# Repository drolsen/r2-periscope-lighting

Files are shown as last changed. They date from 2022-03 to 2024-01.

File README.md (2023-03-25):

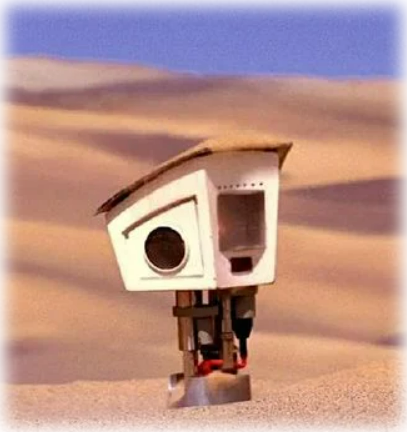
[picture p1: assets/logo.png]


# Open Source R2D2 Periscope Lighting PCB(s)

This open source project is a place to house all information around:
- Purchasing R2D2 periscope lighting PCBs
- Constructing the PCBs
- Uploading Code / Testing & running PCB lights

## Features
- [Deisgned for R2 Uppity Spinner](https://astromech.net/forums/showthread.php?42923-Uppity-Spinner-Periscope-Lifter-and-Rotary-PCB)
- Optional RX/TX communication
- 31x 5v WS2812B-2020 RGB LEDs
- 8 different lighting modes

<!---
## Assembily options

Before you get started on purchasing PCBs, you must first decide if you or the manufacturer will be surface mounting the PCB components. Its recommended you review both assembily options first before making any purchase. In both instances you get 5 whole kits, however one is less expensive than the other but requires more work.

- Minimal amount of soldering / Most Expensive
- Most amount of soldering / Least Expensive route

Minimal amount of soldering assembily option is the most expensive option cause the PCB circiut board manufacturer will be doing all the component (RGB LED, capacitors, resitors) for you under a 4 design x5 board run. This leaves you with only having to break out each PCB side, dry fitting them and soldering the through holes where each side edges meet. Upload code, apply power and away you go.

However the cheaper option requires the most amount of soldering and that you have experince at SMD soldering. Instead of the manufacturer doing the soldering you are given a metal stencile that is used in conjunction with low temp solder, heat gun or plate to surface mount self purchased components. This all before even assembiling the sides together, mounting arduino, uploading code and applying power.
-->

<!---## Ordering Guides

- Quick Assembly PCB Order Option (https://github.com/drolsen/r2-periscope-lighting/wiki/Ordering-PCBs)
 Complex Assembily PCB Order Option (https://github.com/drolsen/r2-periscope-lighting/wiki/PCB-Ordering-(Complex-Assembly)) -->

## Guides

All the gudies on ordering and assembly can be found in the wiki of this github repo:
https://github.com/drolsen/r2-periscope-lighting/wiki

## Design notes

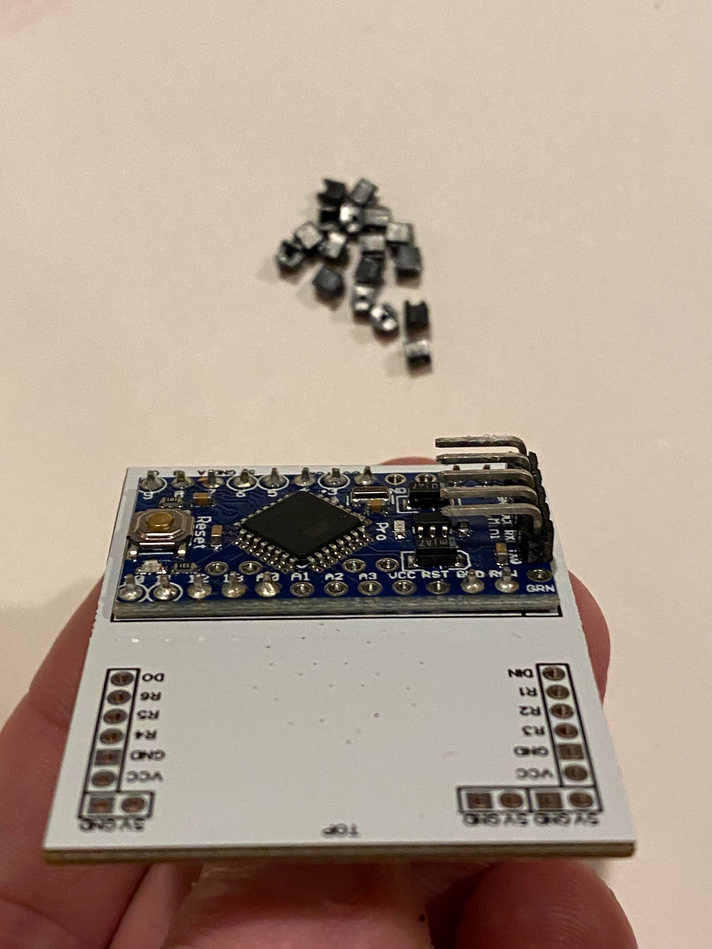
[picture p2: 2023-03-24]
assets/330232331_593315286163290_5333872589423925475_n.jpg

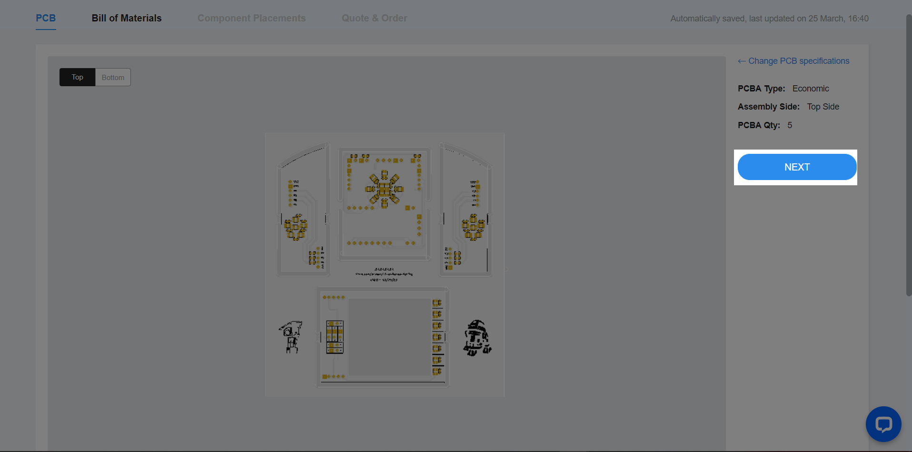
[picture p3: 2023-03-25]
assets/fab-04a.jpg

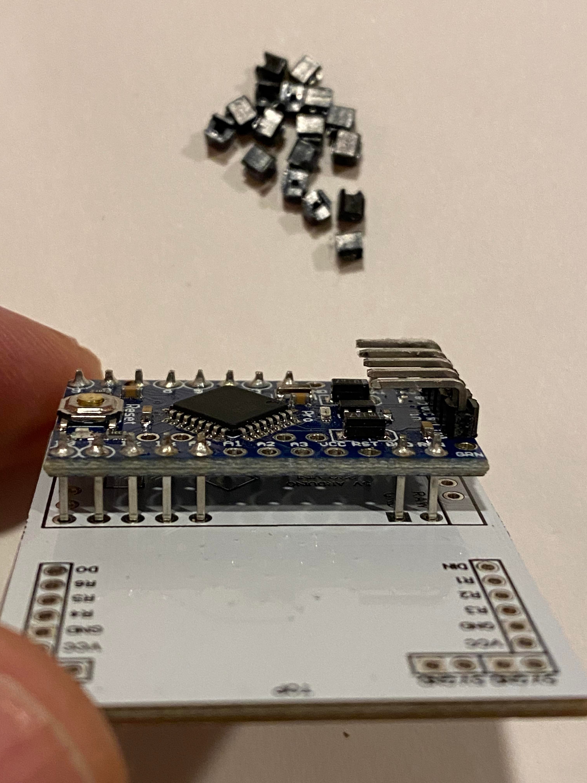
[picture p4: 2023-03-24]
assets/336629106_527774112630229_1906755230113006917_n.jpg

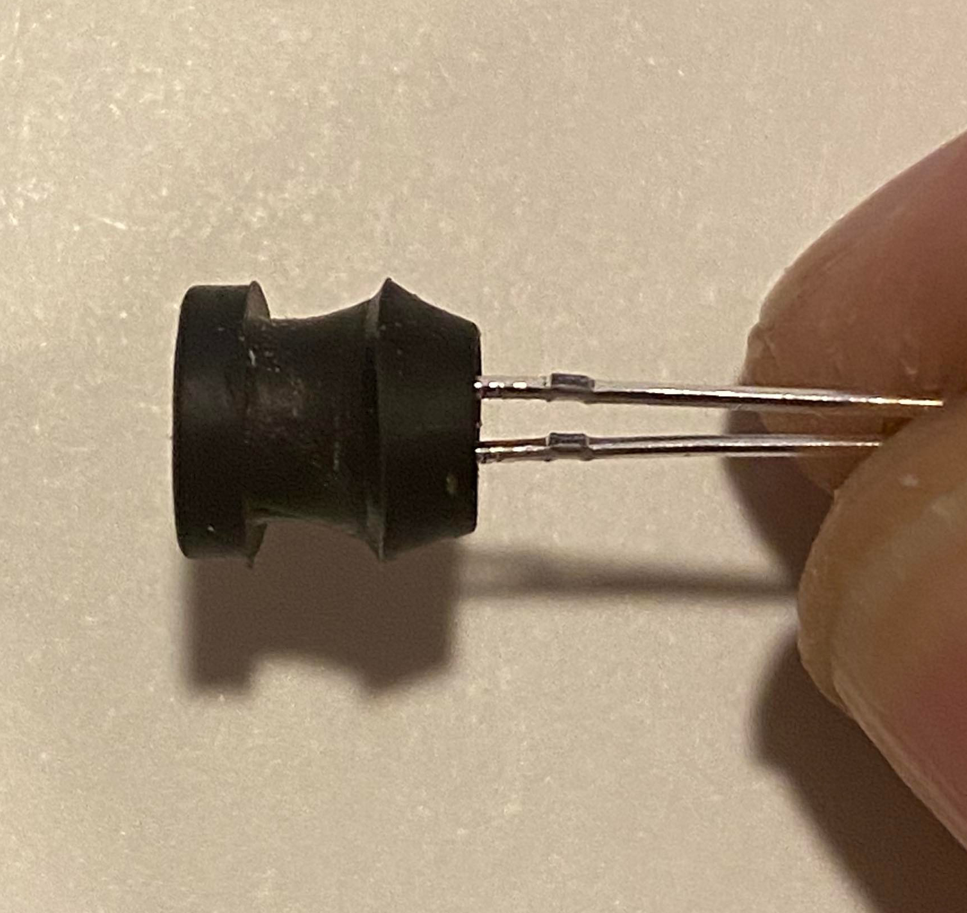
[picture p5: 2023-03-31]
assets/337446692_172143675710304_596749577539224145_n.jpg

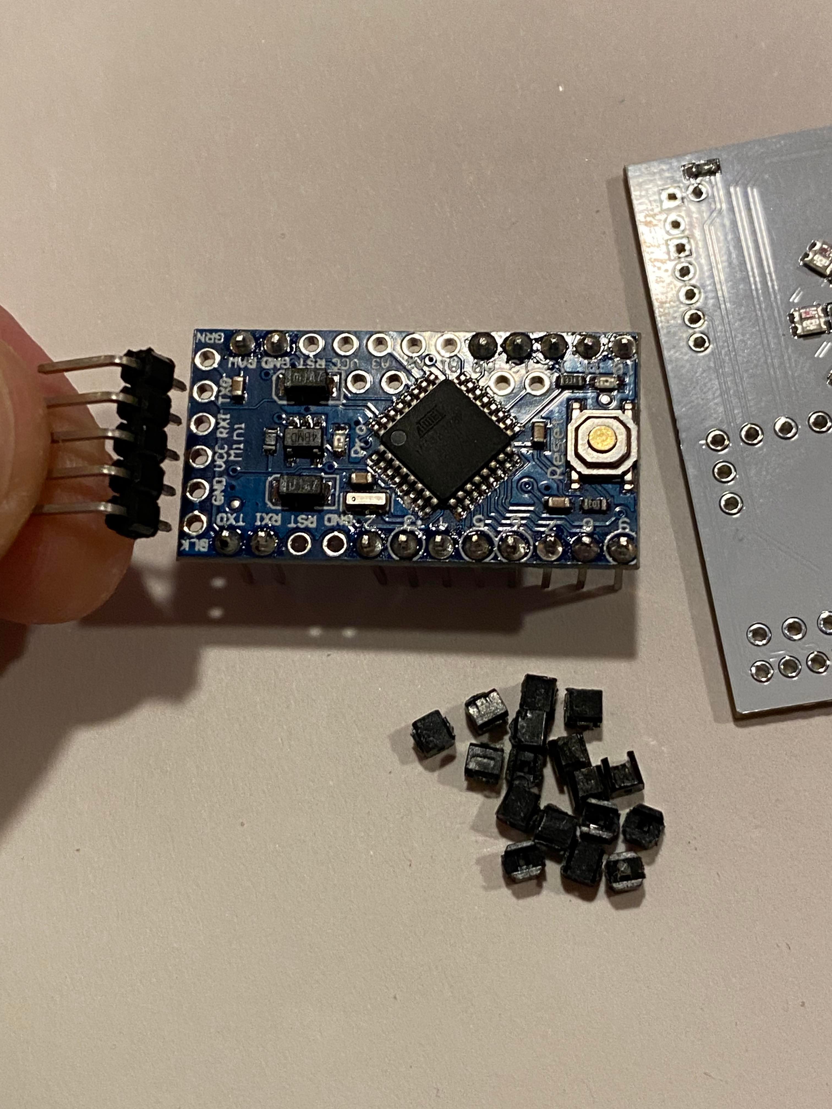
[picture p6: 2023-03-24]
assets/336670627_171413809047904_7290120640967253757_n.jpg

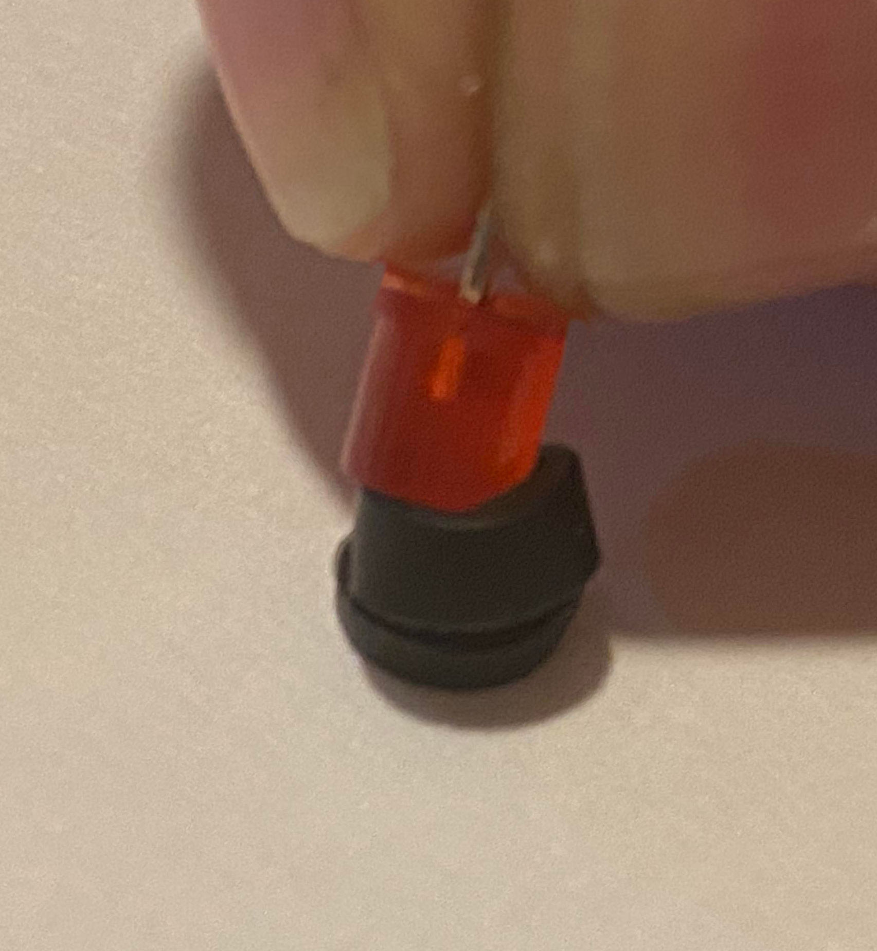
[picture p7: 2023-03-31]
assets/337642645_714867343767022_3792772655546986690_n.jpg

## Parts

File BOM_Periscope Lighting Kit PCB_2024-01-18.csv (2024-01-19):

ID | Name | Designator | Footprint | Quantity | Manufacturer Part | Manufacturer | Supplier | Supplier Part | Price
1 | LED-SMD_4P-L2.0-W2.0-TL_WS2812B-2020 | LED28,LED27,LED45,LED46,LED47,LED48,LED49,LED50,LED51,LED52,LED53,LED17,LED22,LED23,LED24,LED25,LED26,LED43,LED44,LED18,LED19,LED20,LED21,LED42,LED36,LED35,LED34,LED33,LED32,LED31,LED30 | LED-SMD_4P-L2.0-W2.0-TL_WS2812B-2020 | 31 | WS2812B-2020 | Worldsemi | LCSC | C965555 | 0.1
2 | C0402 | C1,C60,C61,C62,C63,C64,C65,C66,C67,C68,C69,C70,C71,C72,C73,C74,C75,C76,C77,C78,C79,C80,C81,C82,C83,C84,C85,C86,C87,C88,C89 | C0402 | 31 | CSA0402X7R104K250GT | HRE(芯声) | LCSC | C3015120 | 0.001
3 | R0603 | R4,R25,R26,R27,R28,R29,R30,R31,R32 | R0603 | 9 | RC0603FR-07150RL | YAGEO(国巨) | LCSC | C114608 | 0.001

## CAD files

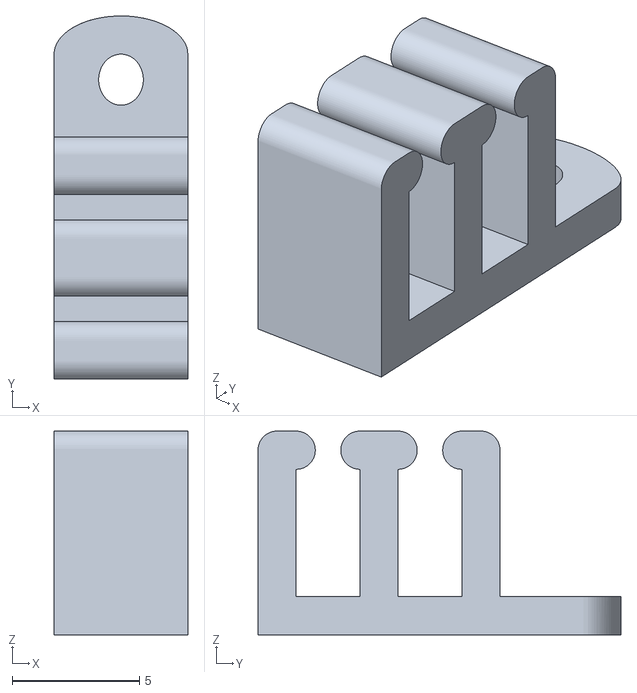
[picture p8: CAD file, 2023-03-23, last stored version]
models/Dome - STL/Holoprojector/Comb HP 2-B.stl
5.25 x 14.2 x 8.00

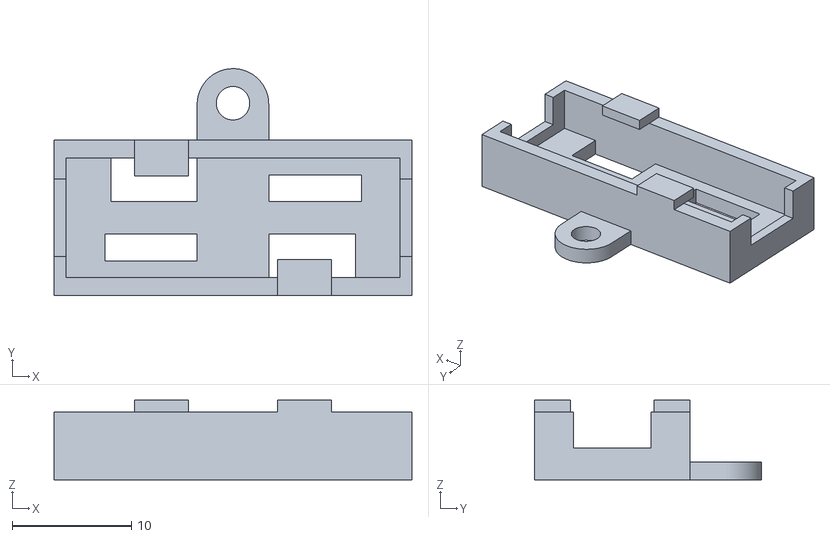
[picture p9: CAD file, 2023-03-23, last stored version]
models/Dome - STL/Servo Clips/Servoclip Mod1 - 1.stl
30.0 x 19.0 x 6.70

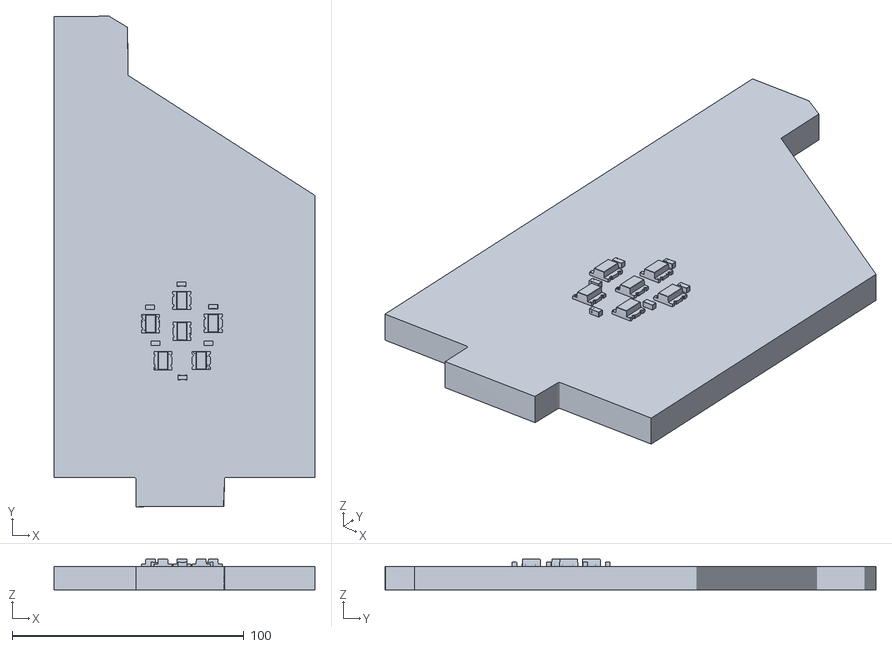
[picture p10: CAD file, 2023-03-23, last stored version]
models/OBJ_SideB.obj
112.5 x 211.4 x 13.3

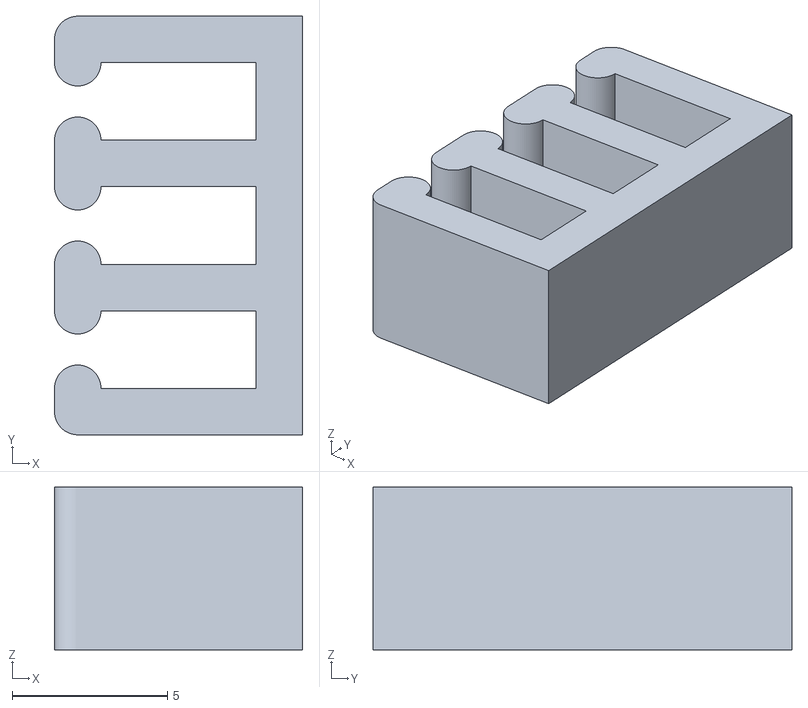
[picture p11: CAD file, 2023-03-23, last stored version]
models/Dome - STL/Combs/Comb 3x1 rev0.stl
8.00 x 13.5 x 5.25

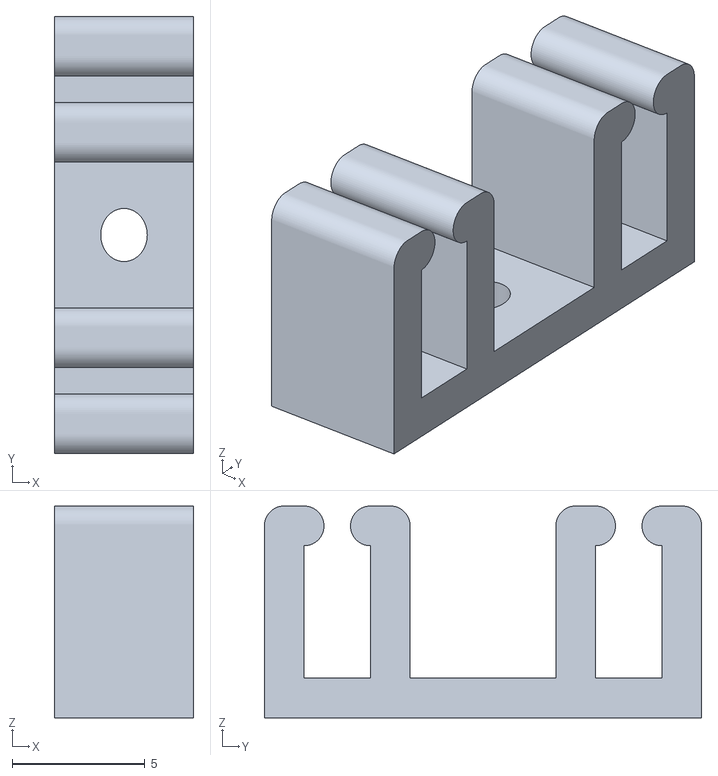
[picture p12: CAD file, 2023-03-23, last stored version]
models/Dome - STL/Holoprojector/Comb HP 2-B-2.stl
5.25 x 16.5 x 8.00

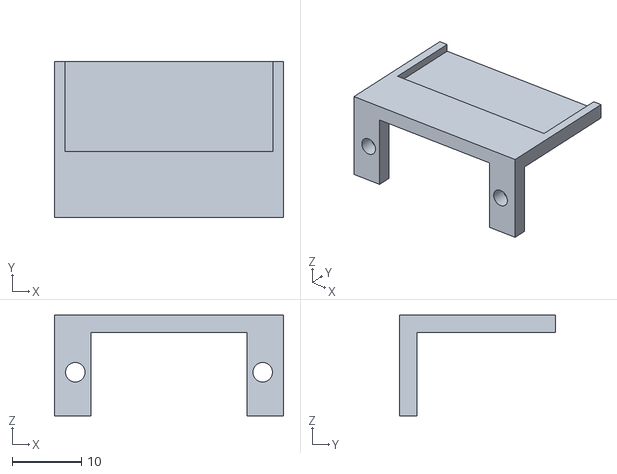
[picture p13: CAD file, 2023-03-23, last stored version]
models/Dome - STL/Servo Clips/Servoclip Base 1.stl
33.0 x 22.5 x 14.5

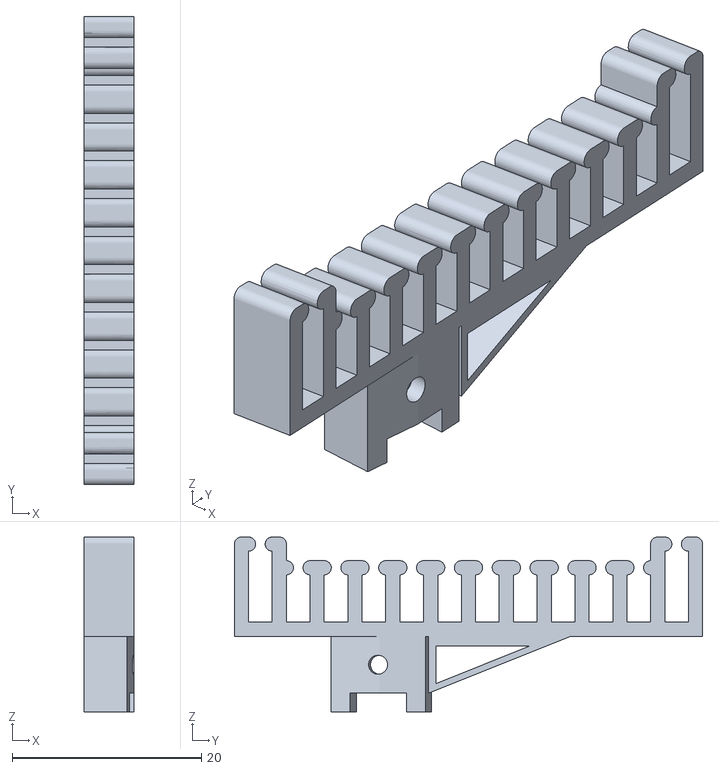
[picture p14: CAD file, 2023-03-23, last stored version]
models/Dome - STL/Tower & Combs/Tower Comb - Right11 Rev6.stl
5.25 x 49.5 x 18.5

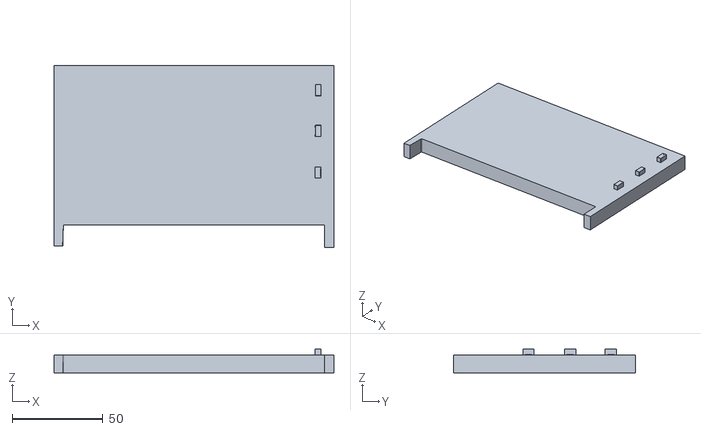
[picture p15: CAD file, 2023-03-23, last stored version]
models/OBJ_TopA.obj
153.9 x 99.9 x 13.1

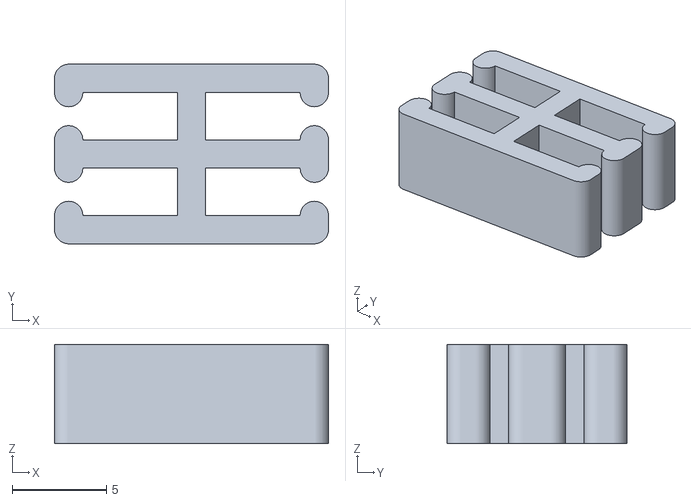
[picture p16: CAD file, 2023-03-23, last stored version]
models/Dome - STL/Combs/Comb 2x2 rev0.stl
14.5 x 9.50 x 5.25

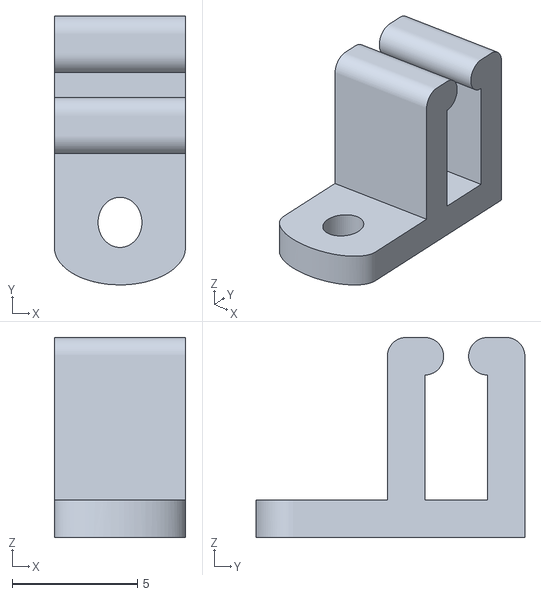
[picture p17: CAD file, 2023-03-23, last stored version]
models/Dome - STL/Holoprojector/Comb HP 1-B.stl
5.25 x 10.8 x 8.00

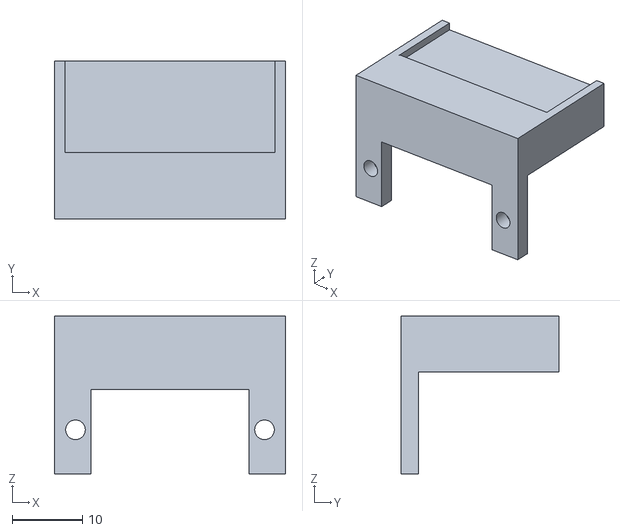
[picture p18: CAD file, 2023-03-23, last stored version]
models/Dome - STL/Servo Clips/Servoclip Base 1 - Tall.stl
33.0 x 22.5 x 22.5

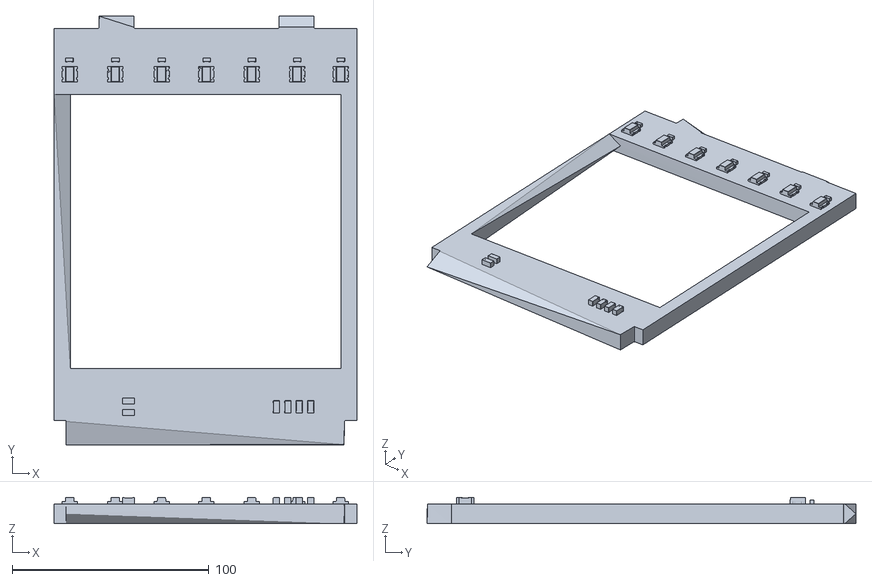
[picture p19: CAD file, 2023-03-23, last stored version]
models/OBJ_Front.obj
153.9 x 217.8 x 13.3

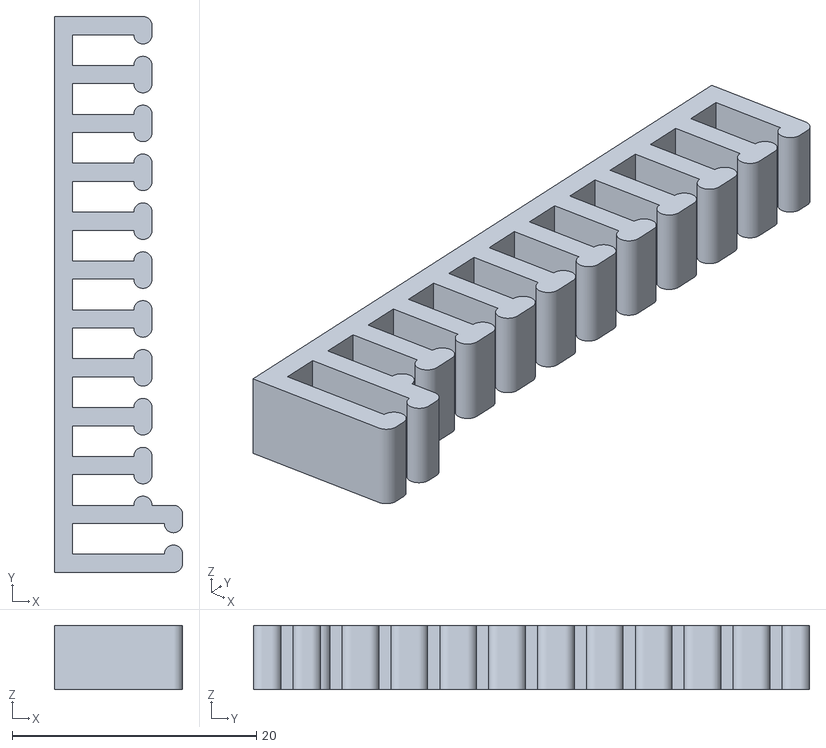
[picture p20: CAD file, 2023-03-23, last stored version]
models/Dome - STL/Combs/Comb 10x1 rev1.stl
10.5 x 45.5 x 5.25

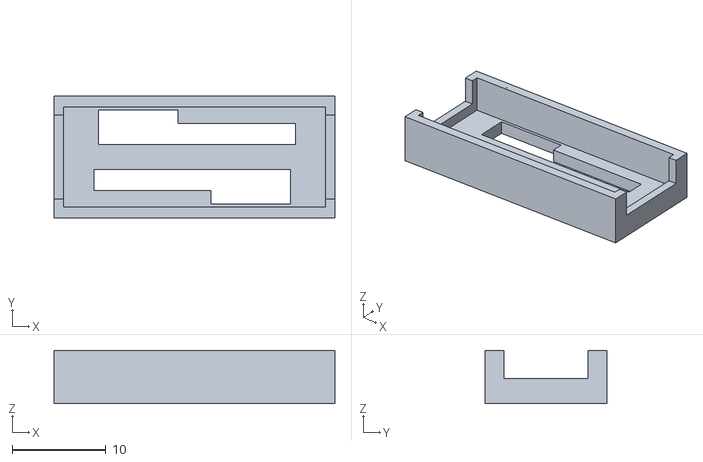
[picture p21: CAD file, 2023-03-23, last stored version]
models/Dome - STL/Servo Clips/Servoclip version2.stl
30.0 x 13.0 x 5.70

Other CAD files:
models/Dome - STL/Tower & Combs/Tower Comb - Left10 Rev5.stl
models/OBJ_Bottom.obj
models/Dome - STL/Combs/Comb 5x2 rev0.stl
models/Dome - STL/Servo Clips/Servoclip Base 2.stl
models/Dome - STL/Combs/Comb 10x1 rev0.stl
models/Dome - STL/Servo Clips/Servoclip Mod1 - 2.stl
models/Dome - STL/Servo Clips/Servoclip original.stl
models/Dome - STL/Tower & Combs/Tower - Empty Pie.stl
models/Dome - STL/Tower & Combs/Tower - Panel 13 Rev1.stl
models/Dome - STL/Tower & Combs/Tower - Panel 13 Rev2.stl
models/Dome - STL/Tower & Combs/Tower - Panel 13 Rev3.stl
models/Dome - STL/Tower & Combs/Tower - Pie Panel Rev4.stl
models/Dome - STL/Tower & Combs/Tower - Pie Panel Rev5.stl
models/Dome - STL/Tower & Combs/Tower Comb - Left10 Rev4.stl
models/Dome - STL/Tower & Combs/Tower Comb - Left11 Rev6.stl
models/Dome - STL/Tower & Combs/Tower Comb - Right10 Rev4.stl
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

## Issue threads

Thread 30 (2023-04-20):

Voltage Regulator Issue

drolsen, 2023-04-20:
Versions 1.0.0 - 1.0.1 have their power in being ran to RAW / GND pins on arduino.
However due to RAW pin being voltage regulated to 5v, most of (if not all) users with this who are feeding a 5v will see a less than 5v out on RED leds.

v1.1.0 will now use the VCC / GND pins on arduino.
This will no longer regulate the power for users, and assumes users will be only supplying 5v (no longer a range of 5v-12v). As a result of no longer doubly regulating power RED LEDs will be running at a solid 5v and tad brighter.

drolsen, 2023-04-20:
This change has been release at v 1.1.0.
Should be ready to close.

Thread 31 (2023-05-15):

FTDI pins

SkyJetty, 2023-05-15:
The back PCB needs 2 more holes to fit the full 6 pin FTDI cable attachment header on the Pro Mini.   I had to modify my FTDI cable to programed this instead of just plugging it in like I have on every other pro mini ever used...   Add 2 more holes so the 6 pin header will fit.

drolsen, 2024-01-19:
Both caps and resistor suppliers went dry.
I've updated the files to include more readily available suppliers for these two components under release 1.4.1.

Thanks!

Closed 2024-01-19.

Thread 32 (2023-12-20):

Errors while ordering Periscope Lighting Kit

GalaxyGuy4, 2023-12-20:
First off all, thanks for having these available.

Following your step by step procedure to order the boards, I ran into an issue with 2 of the 3 line items on the BOM. See attached screenshot for errors presented during BOM page.

Steps followed:
https://github.com/drolsen/r2-periscope-lighting/wiki/Ordering-PCBs

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

Thanks,

drolsen, 2024-01-19:
Both caps and resistor suppliers went dry.
I've updated the files to include more readily available suppliers for these two components under release 1.4.1.

Thanks!

Closed 2024-01-19.

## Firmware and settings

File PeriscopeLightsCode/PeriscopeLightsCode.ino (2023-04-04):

//////////////////////////////////////////////////////
//     R-Series Periscope Lighting Kit Sketch       // 
//          (Devin R. Olsen - 3/31/2023)            //
// https://github.com/drolsen/r2-periscope-lighting //
//////////////////////////////////////////////////////

// Configurable options
int BRIGHTNESS = 250;     // Defines the brightness of RGB leds (255 max / 200 recommended)
byte COMTYPE = 0;         // 0 === Legacy three pin ABC communication | 1 === RX/TX serial communication (requires RX/TX pads be soldered on top PCB)
byte MODE = 1;            // 1 == FullCycle | 2 == FullOff | 3 == ObiWanLights | 4 == YodaLights | 5 == SithLights | 6 == SearchLights | 7 == DagobahLights | 8 == SparkelLights | 9 == FullOn | 10 = COM Debug

// Mode Speeds (smaller numbers is faster)
int ObiwanSpeed = 5;        // Speed Obiwan lights mode
int YodaSpeed = 5;          // Speed Yoda lights mode
int SithSpeed = 5;          // Speed Sith lights mode
int SearchSpeed = 45;       // Speed Search lights mode
int DagobahSpeed = 500;     // Speed Degobah lights mode
int SparkelSpeed = 50;      // Speed Sparkel lights mode

// Durations (smaller numbers is faster)
int FullCycleDuration = 10000;    // Duration between each mode
int REDFrontDuration = 900;       // Duration between each RED front LEDs lighting up
int REDBackDuration = 1000; // Duration between random on/off states for RED back LEDs

// All Colors in RGB format
int RED[3] = {255, 0, 0};
int GREEN[3] = {0, 255, 0};
int BLUE[3] = {0, 0, 255};
int LISBORN[3] = {20, 20, 10};
int VIOLET[3] = {189, 51, 255};
int DARKVIOLET[3] = {35, 5, 45};
int WHITE[3] = {255, 255, 255};
int BLACK[3] = {0, 0, 0};

// Mode's Used Colors
int ObiwanColors[2] =   {BLUE, WHITE};
int YodaColors[2] =     {GREEN, LISBORN};
int SithColors[2] =     {RED, LISBORN};
int SearchColors[2] =   {WHITE, DARKVIOLET};
int DagobahColors[2] =  {VIOLET, WHITE};
int SparkelColors[2] =  {VIOLET, WHITE};

//////////////////////////////////////
// Do not change the settings below //
//////////////////////////////////////
#include <Adafruit_NeoPixel.h>
#define RGBPin 14     // Data pin number for LEDS
#define RGBCount 31   // How many RGB LEDS on Lights
Adafruit_NeoPixel RGBLEDS(RGBCount, RGBPin, NEO_GRB + NEO_KHZ800);

byte RGBAllSides[2] = {12, 30};
byte RGBCenter[2] = {0, 11};  // Center RGB Pixel Range
byte RGBLeft[2] = {12, 17};   // Left RGB Pixel Range
byte RGBFront[2] = {18, 24};  // Front RGB Pixel Range
byte RGBRight[2] = {25, 30};  // Right RGB Pixel Range

// RED LED PINS
byte REDBack[2] = {11, 13};   // Back RED LED Range
byte REDFront[2] = {2, 7};    // Front RED LED Range

// COM PINS
byte MODETEST;
#define COM0 8
#define COM1 9
#define COM2 10

// Non-delay Wait Timestamp Helpers
unsigned long REDBackWait = millis();
unsigned long REDFrontWait = millis();
unsigned long CenterWait = millis();
unsigned long LeftWait = millis();
unsigned long FrontWait = millis();
unsigned long RightWait = millis();
unsigned long FullCycleWait = millis();

// States (Helpers used as flip-flop or reference current states)
byte REDBackCurrent = REDBack[0];
byte REDFrontCurrent = REDFront[0];
byte CenterLEDSCurrent = RGBCenter[0];
byte LeftLEDSCurrent = RGBLeft[0];
byte FrontTopLEDSCurrent = RGBFront[0];
byte RightLEDSCurrent = RGBRight[0];
byte FullCycleCurrent = 3;

byte CenterDirection = 1;       // 0 = move up / 1 = move down
byte LeftDirection = 1;         // 0 = move up / 1 = move down
byte FrontTopDirection = 1;     // 0 = move up / 1 = move down
byte RightDirection = 1;        // 0 = move up / 1 = move down
byte REDFrontDirection = 1;     // 0 = move left / 1 = move right

int FrontRGBState[3] = {0, 0, 0};
int LeftRGBState[3] = {0, 0, 0};
int RightRGBState[3] = {0, 0, 0};
int CenterRGBState[3] = {0, 0, 0};

void setup() {
  if (COMTYPE == 1) {
    Serial.begin(9600);
    Serial.setTimeout(50);
  }
  
  // A, B, C three pin communication    
  pinMode(COM0, INPUT_PULLUP);
  pinMode(COM1, INPUT_PULLUP);
  pinMode(COM2, INPUT_PULLUP);

  for (byte i = 2; i <= 7; i++) {
    pinMode(i, OUTPUT);
    // digitalWrite(i, HIGH);
  }

  for (byte i = 11; i <= 13; i++) {
    pinMode(i, OUTPUT);
    // digitalWrite(i, HIGH);
  }  

  RGBLEDS.begin();
  RGBLEDS.show();
  RGBLEDS.setBrightness(BRIGHTNESS); // Set pixel brightness defined above
}

void loop() {
  // COMs Checking
  if (MODE != 10) { COMCheck(); }

  // Full Cycle
  if (MODE == 1) { FullCycle(); }
  
  // Full Off
  if (MODE == 2) { Off(); }

  // Obi Wan Lights
  if (MODE == 3) { ObiWanLights(); }

  // Yoda Lights
  if (MODE == 4) { YodaLights(); }

  // Sith Lights
  if (MODE == 5) { SithLights(); }

   // Search Light
  if (MODE == 6) { SearchLights(); }

  // Dagobah Lights
  if (MODE == 7) { DagobahLights(); } 

  // Lights Sparkel
  if (MODE == 8) { SparkelLights(); }

  // Debug LEDS (used to debug if all leds light up)
  if (MODE == 9) { DebugLights(); }

  // Debug COMS (used to identify HIGH or LOW states of ABC pins)
  if (MODE == 10) { DebugComs(); }    
}


////////////////////
// HELPER METHODS //
////////////////////
// Checks COM for different light modes
void COMCheck() {
  ///////////////////////////
  // ABC Pin COMMUNICATION //
  ///////////////////////////
  int COMBOS[8][3] = {
    {1, 1, 1},   // Full Cycle
    {1, 1, 0},   // Full Off
    {1, 0, 1},   // Obi Wan Lights
    {1, 0, 0},   // Yoda Lights
    {0, 1, 1},   // Sith Lights
    {0, 1, 0},   // Search Light
    {0, 0, 1},   // Dagobah Lights
    {0, 0, 0}    // Lights Sparkel
  };
  
  if (COMTYPE == 0) {
    // Find a match in our COMBOS array
    for (byte i = 0; i <= 7; i++) {
      if (
        digitalRead(COM0) == COMBOS[i][0] 
        && digitalRead(COM1) == COMBOS[i][1] 
        && digitalRead(COM2) == COMBOS[i][2]
      ) {
        MODE = (i+1); // Cause mode is not zero based
      }
    }
  } else {
    //////////////////////////////////////
    // Alternative RX/TX COMMUNICATION  //
    //////////////////////////////////////
    if (Serial.available()) {
      // Listening variable
      String command = Serial.readStringUntil('\n'); 

      if ((sizeof(command)-1) > 0) {
        // Qualifiers
        String commands[9] = {
          ":PL1", ":PL2", ":PL3", 
          ":PL4", ":PL5", ":PL6", 
          ":PL7", ":PL8", ":PL9"
        };
        
        // Checking
        for (int i = 1; i <= 9; i++) {
          if (command.equals(commands[i - 1])) {
            MODE = i;
            break; // lets stop seeking
          }
        } 
      }     
    }
  }
}

// Debug LEDs
void DebugLights() {
  // Light up all RGB LEDs as blue
  for (int i = 0; i < RGBCount; i++) {
    RGBLEDS.setPixelColor(i, 0, 0, 255);
  }

  // Show pixel's change
  RGBLEDS.show();
  
  // Turn on all RED back LEDs
  for (byte i = REDBack[0]; i <= REDBack[1]; i++) {
    digitalWrite(i, HIGH);
  }
  
  // Turn on all RED front LEDs
  for (byte i = REDFront[0]; i <= REDFront[1]; i++) {
    digitalWrite(i, HIGH);
  }
}

// Debug COMs (ABC Pin debuging)
void DebugComs(){
  if (digitalRead(COM0) == 1) {
    RGBLEDS.fill(RGBLEDS.Color(255, 255, 255), RGBRight[0], ((RGBRight[1] - RGBRight[0]) + 1));
  } else {
    RGBLEDS.fill(RGBLEDS.Color(0, 0, 0), RGBRight[0], ((RGBRight[1] - RGBRight[0]) + 1));
  }

  if (digitalRead(COM1) == 1) {
    RGBLEDS.fill(RGBLEDS.Color(255, 255, 255), RGBCenter[0], ((RGBCenter[1] - RGBCenter[0]) + 1));
  } else {
    RGBLEDS.fill(RGBLEDS.Color(0, 0, 0), RGBCenter[0], ((RGBCenter[1] - RGBCenter[0]) + 1));
  }

  if (digitalRead(COM2) == 1) {
    RGBLEDS.fill(RGBLEDS.Color(255, 255, 255), RGBLeft[0], ((RGBLeft[1] - RGBLeft[0]) + 1));
  } else {
    RGBLEDS.fill(RGBLEDS.Color(0, 0, 0), RGBLeft[0], ((RGBLeft[1] - RGBLeft[0]) + 1));
  }

  RGBLEDS.show();   
}

// Clearing LEDs
void Clear(byte side[2], int bgColor[3], bool isDigital) {
  if (isDigital) {
    for (int i = side[0]; i <= side[1]; i++) {
      digitalWrite(i, LOW);
    }
  } else {
    if (bgColor) {
      RGBLEDS.fill(RGBLEDS.Color(bgColor[0], bgColor[1], bgColor[2]), side[0], ((side[1] - side[0]) + 1));
    } else {
      RGBLEDS.fill(RGBLEDS.Color(0, 0, 0), side[0], ((side[1] - side[0]) + 1));
    }
  }
}

///////////////////////
// ANIMATION METHODS //
///////////////////////

// On / Off
void On(int rgb[3], byte side[2]){
  if (rgb != NULL) {
    for (byte i = side[0]; i <= side[1]; i++){
      RGBLEDS.setPixelColor(i, RGBLEDS.Color(rgb[0], rgb[1], rgb[2]));    
    }
    RGBLEDS.show();
  } else {
    for (byte i = side[0]; i <= side[1]; i++){
      digitalWrite(i, HIGH);    
    }    
  }
}

void Off() {
  for (byte i = 0; i <= RGBCount; i++) {
    RGBLEDS.setPixelColor(i, RGBLEDS.Color(0, 0, 0));   
  }
  RGBLEDS.show();
  
  Clear(REDFront, NULL, true);
  Clear(REDBack, NULL, true); 
}

// Sweeps 
void FullSweep(int rgb[3], int bgColor[3], int delay, unsigned long& wait) {
  byte SweepSequence[17][6] = {
    {28},         // left
    {28, 29},
    {27, 26},
    {31, 30},
    {31},
    {3, 25},          // center & front top
    {2, 4, 24},
    {1, 10, 11, 5, 23},
    {1, 9, 12, 5, 22},
    {6, 9, 12, 5, 21},
    {8, 6, 20},
    {7, 19},
    {18},         // right
    {18, 17},
    {14, 13},
    {15, 16},
    {15}
  };

  if (millis() > (wait + delay)) {
    // Change Direction
    if (CenterDirection == 1) {
      CenterLEDSCurrent++;
      if (CenterLEDSCurrent > 15) { CenterDirection = 0; }
    } else {
      CenterLEDSCurrent--; 
      if (CenterLEDSCurrent <= 0) { CenterDirection = 1; }  
    }
    
    // First, lets set all LEDS to BG color
    for (int i = 0; i < RGBCount; i++) {
      RGBLEDS.setPixelColor(i, 
        RGBLEDS.Color(
          bgColor[0], 
          bgColor[1], 
          bgColor[2]
        )
      );
    }
    RGBLEDS.show();
    
    // Second, lets loop over squence array and define set sweep color
    for (int i = 0; i < 5; i++) {
      if (SweepSequence[CenterLEDSCurrent][i]) {
        RGBLEDS.setPixelColor(
          (SweepSequence[CenterLEDSCurrent][i] - 1), 
          RGBLEDS.Color(
            rgb[0], 
            rgb[1], 
            rgb[2]
          )
        );
      }
    }       
    RGBLEDS.show();
    wait = millis();
  }
}

// Left to right sweeps
void FrontSweepLTR(int rgb[3], int delay, unsigned long& wait) {
  if (millis() > (wait + delay)) {
    // Change Direction
    if (FrontTopDirection == 1) {
      FrontTopLEDSCurrent++;
      if (FrontTopLEDSCurrent == 24) { FrontTopDirection = 0; }    
    } else {
      FrontTopLEDSCurrent--; 
      if (FrontTopLEDSCurrent == 18) { FrontTopDirection = 1; }    
    }    
    
    // First turn off all front LEDS
    Clear(RGBFront, NULL, false);
    RGBLEDS.setPixelColor(FrontTopLEDSCurrent, RGBLEDS.Color(rgb[0], rgb[1], rgb[2]));
    
    // Reset timestamp checking
    RGBLEDS.show();
    wait = millis();
  }
}

void REDFrontSweepLTR() {
  if (millis() > (REDFrontWait + REDFrontDuration)) {

    byte sequence[6] = { 4, 3, 2, 5, 6, 7 };
    // First turn off all front LEDS
    Clear(REDFront, NULL, true);
        
    // Increase current front RED LED
    if (REDFrontDirection == 1) {
      REDFrontCurrent++;
      if (REDFrontCurrent == 5) { REDFrontDirection = 0; }    
    } else {
      REDFrontCurrent--; 
      if (REDFrontCurrent == 0) { REDFrontDirection = 1; }    
    }

    Serial.println(sequence[REDFrontCurrent]);
    
    digitalWrite(sequence[REDFrontCurrent], HIGH);

    // Reset timestamp checking
    REDFrontWait = millis();
  }
}

// Left & Right to Center sweeps
void FrontSweepLRTC(int rgb[3], int delay, unsigned long& wait) {
  if (millis() > (wait + delay)) {
    // Change Direction
    byte SweepSequence[4][2] = {
      {18, 24},
      {19, 23},
      {20, 22},
      {21, 21}
    };
    
    if (FrontTopDirection == 1) {
      FrontTopLEDSCurrent++;
      if (FrontTopLEDSCurrent == 3) { FrontTopDirection = 0; }    
    } else {
      FrontTopLEDSCurrent--; 
      if (FrontTopLEDSCurrent == 0) { FrontTopDirection = 1; }    
    }    
    
    // First turn off all front LEDS
    Clear(RGBFront, NULL, false);
    RGBLEDS.setPixelColor(SweepSequence[FrontTopLEDSCurrent][0], RGBLEDS.Color(rgb[0], rgb[1], rgb[2]));
    RGBLEDS.setPixelColor(SweepSequence[FrontTopLEDSCurrent][1], RGBLEDS.Color(rgb[0], rgb[1], rgb[2]));
    
    // Reset timestamp checking
    RGBLEDS.show();
    wait = millis();
  }
}

// Randoms
void Random(int rgb[3], int background[3], byte side[2], int delay, unsigned long& wait) {
  if (millis() > (wait + delay)) {
    Clear(side, background, false);
    
    int randomA = random(side[0], (side[1]+1));
    int randomB = random(side[0], (side[1]+1));
    
    // For random dual color instances
    while (randomB == randomA) {
      randomB = random(side[0], (side[1]+1));
    }

    RGBLEDS.setPixelColor(
      randomA, 
      RGBLEDS.Color(
        rgb[0], 
        rgb[1], 
        rgb[2]
      )
    );
    
    RGBLEDS.setPixelColor(
      randomB, 
      RGBLEDS.Color(
        rgb[0], 
        rgb[1], 
        rgb[2]
      )
    );

    RGBLEDS.show();
    wait = millis();
  }
}

void REDBackRandom() {
  if (millis() > (REDBackWait + REDBackDuration)) {
    Clear(REDBack, NULL, true);
    REDBackCurrent = random(11, 14);
    digitalWrite(REDBackCurrent, HIGH);

    REDBackWait = millis();
  }  
}

// Fades
void Fade(int rgb[3], int rgbState[3], byte side[2], byte& direction, int delay, unsigned long& wait) {
  if (millis() > (wait + delay)) {
    if (rgbState[0] > rgb[0]) { rgbState[0] = 0; }
    if (rgbState[1] > rgb[1]) { rgbState[1] = 0; }
    if (rgbState[2] > rgb[2]) { rgbState[2] = 0; }

    if (direction == 0) {
      if (rgbState[0] > 0) { rgbState[0]--; }
      if (rgbState[1] > 0) { rgbState[1]--; }
      if (rgbState[2] > 0) { rgbState[2]--; }
  
      if (
        rgbState[0] == 0 
        && rgbState[1] == 0 
        && rgbState[2] == 0
      ) {
        direction = 1;
      }
    }

    if (direction == 1) {
      if (rgbState[0] < rgb[0]) { rgbState[0]++; }
      if (rgbState[1] < rgb[1]) { rgbState[1]++; }
      if (rgbState[2] < rgb[2]) { rgbState[2]++; }
  
      if (
        rgbState[0] == rgb[0] 
        && rgbState[1] == rgb[1] 
        && rgbState[2] == rgb[2]
      ) {
        direction = 0;
      }
    }

    RGBLEDS.fill(RGBLEDS.Color(rgbState[0], rgbState[1], rgbState[2]), side[0], ((side[1] - side[0]) + 1));
    RGBLEDS.show(); 
    wait = millis();
  }
}

////////////////////
// MODE SEQUENCES //
////////////////////
void FullCycle() {
  if (millis() > (FullCycleWait + FullCycleDuration)) {
    FullCycleCurrent++;
    
    if (FullCycleCurrent > 8) { FullCycleCurrent = 3; }
    
    FullCycleWait = millis();
  }

  if (FullCycleCurrent == 3) { ObiWanLights(); }
  if (FullCycleCurrent == 4) { YodaLights(); }
  if (FullCycleCurrent == 5) { SithLights(); }
  if (FullCycleCurrent == 6) { SearchLights(); }
  if (FullCycleCurrent == 7) { DagobahLights(); }
  if (FullCycleCurrent == 8) { SparkelLights(); }
}

void ObiWanLights() {
  On(BLUE, RGBRight);
  On(BLUE, RGBLeft);   
  Fade(ObiwanColors[0], FrontRGBState, RGBFront, FrontTopDirection, ObiwanSpeed, FrontWait);
  REDFrontSweepLTR();
  REDBackRandom();
  Random(ObiwanColors[1], ObiwanColors[0], RGBCenter, (ObiwanSpeed * 25), CenterWait);
}

void YodaLights() {
  Fade(YodaColors[0], LeftRGBState, RGBLeft, LeftDirection, YodaSpeed, LeftWait);
  Fade(YodaColors[0], RightRGBState, RGBRight, RightDirection, YodaSpeed+1, RightWait);
  Fade(YodaColors[0], FrontRGBState, RGBFront, FrontTopDirection, YodaSpeed+2, FrontWait);
  REDFrontSweepLTR();
  REDBackRandom();
  Random(YodaColors[0], YodaColors[1], RGBCenter, (YodaSpeed * 20), CenterWait);
}

void SithLights() {
  Fade(SithColors[0], LeftRGBState, RGBLeft, LeftDirection, SithSpeed, LeftWait);
  Fade(SithColors[0], RightRGBState, RGBRight, RightDirection, SithSpeed+2, RightWait);
  Fade(SithColors[0], FrontRGBState, RGBFront, FrontTopDirection, SithSpeed+3, FrontWait);
  REDFrontSweepLTR();
  REDBackRandom();
  Random(SithColors[0], SithColors[1], RGBCenter, (SithSpeed * 51), CenterWait);
}

void SearchLights() {
  FullSweep(SearchColors[0], SearchColors[1], SearchSpeed, CenterWait);
  REDFrontSweepLTR();
  REDBackRandom();  
}

void DagobahLights() {
  FrontSweepLTR(DagobahColors[0], DagobahSpeed, FrontWait); // Sweeps a violet light across top lights at an interval of 1 second
  On(DagobahColors[1], RGBCenter);  
  On(DagobahColors[1], RGBRight);
  On(DagobahColors[1], RGBLeft);
  On(NULL, REDFront);
  REDBackRandom();
}

void SparkelLights() {
  Random(SparkelColors[1], NULL, RGBCenter, SparkelSpeed, CenterWait);
  Random(SparkelColors[0], NULL, RGBLeft, SparkelSpeed, LeftWait);
  Random(SparkelColors[0], NULL, RGBRight, SparkelSpeed, RightWait);
  Random(SparkelColors[0], NULL, RGBFront, SparkelSpeed, FrontWait);
  REDFrontSweepLTR();
  REDBackRandom();
}

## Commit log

2022-03-16 DEV Release: Adding link to square LEDs
2022-03-27 DEV Release: Adding fab-03b for SMS self mounting
2022-03-30 DEV Release: Adding arduino pro mini sketch
2023-03-23 dev: Adding manufacture files for PCBS. Adding blender files for testing. Updating code to latest PCB pixel count.
    [BOM_Periscope Lighting Kit PCB_2023-03-23.csv, Comb 10x1 rev0.stl, Comb 10x1 rev1.stl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]
2023-03-24 Adding latest release files for PCBS. Adding guide screenshots
    [BOM_Periscope Lighting Kit PCB_2023-03-24.csv, PickAndPlace_Periscope Lighting Kit PCB_2023-03-23.csv, PickAndPlace_Periscope Lighting Kit PCB_2023-03-24.csv]
2023-03-24 Dev Release: Removing old unwanted model files / folder
    [Comb 10x1 rev0.stl, Comb 10x1 rev1.stl, Comb 2x2 rev0.stl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]
2023-03-25 Dev: Updates to order process of current version
2023-03-25 Dev: Add updated screenshots and new shots for ordering. Latest gerber, bom and pickplace file.
    [BOM_Periscope Lighting Kit PCB_2023-03-25.csv, PickAndPlace_Periscope Lighting Kit PCB_2023-03-25.csv]
2023-03-28 Dev Release: Fixes COM delay due to Fade animation using inner forloop vs. using clock. Adds more timing and new duration options for users. Tweaks to both legacy and serial COM types now allow both 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
    [PeriscopeLightsCode.ino]
2023-03-28 DEV Release: Revert changes on a few items
    [PeriscopeLightsCode.ino]
2023-03-31 dev: Flips the order of resting through holes of upload pins for pro mini that don't actually connect to anything. Newer screenshots added.
    [BOM_Periscope Lighting Kit PCB_2023-03-31.csv, PickAndPlace_Periscope Lighting Kit PCB_2023-03-31.csv]
2023-03-31 Dev: Adding a new screenshot for upload pin location
2023-04-01 DEV: Adding missing mouse bites to the back PCB gaps on manufactured boards.
    [BOM_Periscope Lighting Kit PCB_2023-04-01.csv, PickAndPlace_Periscope Lighting Kit PCB_2023-04-01.csv]
2023-04-04 DEV: Fixing the sequence order on front leds under production release pins order.
    [PeriscopeLightsCode.ino]
2023-04-04 DEV: Reverting back to origanl default values
    [PeriscopeLightsCode.ino]
2023-04-12 flipping photo around until new batch of PCBs arrive for better pictures
2023-04-12 Adding latest version 1.0.1 to direct download
    [BOM_Periscope Lighting Kit PCB_2023-04-12.csv, PickAndPlace_Periscope Lighting Kit PCB_2023-04-01.csv, PickAndPlace_Periscope Lighting Kit PCB_2023-04-12.csv]
2023-04-20 DEV: Adding order files for v 1.1.0
    [BOM_Periscope Lighting Kit PCB_2023-04-20.csv, PickAndPlace_Periscope Lighting Kit PCB_2023-04-12.csv, PickAndPlace_Periscope Lighting Kit PCB_2023-04-20.csv]
2024-01-19 DEV: Updating suppliers for caps and resistors. Fixing missing missing pins for better FTDI compatibility.
    [BOM_Periscope Lighting Kit PCB_2023-04-20.csv, BOM_Periscope Lighting Kit PCB_2024-01-18.csv, PickAndPlace_Periscope Lighting Kit PCB_2023-04-20.csv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]
